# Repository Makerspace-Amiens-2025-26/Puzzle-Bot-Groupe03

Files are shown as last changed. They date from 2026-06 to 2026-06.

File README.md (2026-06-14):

# Puzzle Bot

## Description

Puzzle Bot est une machine automatisée capable de détecter, saisir et assembler les pièces d'un puzzle. Le projet combine plusieurs domaines techniques : conception mécanique, électronique, programmation, vision par ordinateur et fabrication numérique.

## Objectifs
* Détecter les pièces d'un puzzle à l'aide d'une caméra.
* Identifier leur position et leur orientation.
* Déplacer les pièces grâce à un système robotisé.
* Assembler automatiquement le puzzle.
## Technologies utilisées
* Arduino
* Python
* OpenCV
* Onshape
* Impression 3D 
* Découpe laser
## Structure du projet 
* /CAO : modèles 3D et plans.
* /Code : programmes de contrôle et de vision.
* /Electronique : schémas et câblage.
* /Documentation : rapports, poster et ressources.
## Équipe
* Moutassi joseph 
* Mbognie Donna
* Fokem bracins
* Antoni calvin
* Andy Metogo
* Elsy Kounda
## Ressources
* Documentation du projet
* Modèle Onshape
* Poster de présentation

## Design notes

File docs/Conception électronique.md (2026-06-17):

---
layout: default
nav_order: 2
parent: Conception et prototypage
title: Conception electronique
---

# **II. Conception électronique**

## Câblage et Connexions Électriques

Cette section détaille le branchement de chaque composant, fil par fil, pour permettre de reproduire l'électronique du robot à l'identique.

### 1. Alimentation et Arrêt d'Urgence
Toute la puissance mécanique du robot dépend de la batterie 12,7 V. L'objectif est de pouvoir tout couper d'un seul coup.

* **L'Arrêt d'urgence :** Il est placé en "série" sur le fil positif. 
  * Le fil Rouge (+) provenant de la batterie se branche sur l'entrée du bouton coup de poing.
  * En sortie du bouton, le fil Rouge (+) se divise en deux : un câble part vers le bornier d'alimentation du CNC Shield, et l'autre part vers le bornier d'alimentation de notre carte sur mesure (PCB).
* **La Masse :** Le fil Noir (-) de la batterie est directement relié aux borniers "GND" du CNC Shield et de la carte sur mesure.
* **L'Arduino :** Il est alimenté séparément avec son câble USB classique branché à l'ordinateur (qui fournit le 5 V de sécurité).
  
ing1

### 2. Le Cerveau : Arduino et CNC Shield
Le branchement principal est le plus simple : la carte d'extension **CNC Shield v3** vient simplement s'emboîter directement sur le dessus de la carte **Arduino Uno**. Il faut juste vérifier que toutes les petites broches en métal rentrent bien dans les trous noirs de l'Arduino sans se tordre.

### 3. Les Moteurs de déplacement (Axes X et Y)
Ce sont les gros moteurs (NEMA 17) qui font bouger le robot sur la table.

* **Les Drivers (A4988) :** On enfonce ces petits modules sur les emplacements marqués `X` et `Y` au centre du CNC Shield. *(Attention à mettre la petite vis de réglage du bon côté selon la documentation du module !)*
* **Les Moteurs :** Chaque moteur possède un câble avec un connecteur à 4 fils (les deux bobines internes). Ils viennent se brancher directement sur les 4 petites broches alignées juste à côté de leur driver A4988 respectif. Notez à inverser les deux fils du milieu.

ing1

### 4. La Tête de Préhension (Les 2 Servomoteurs)
Les deux servomoteurs (MG996R) qui gèrent la descente et la rotation de la ventouse possèdent 3 fils chacun :

* **Fil Rouge (Énergie) :** À brancher sur une broche **5V** libre du CNC Shield.
* **Fil Marron ou Noir (Masse) :** À brancher sur une broche **GND** du CNC Shield.
* **Fil Jaune ou Orange (Signal) :** C'est le fil qui transporte les ordres. Puisque les broches classiques sont déjà utilisées, on les branche sur des broches libres capables de faire varier la tension (PWM). Par exemple, le premier sur la broche **5** et le deuxième sur la broche **6**.

ing1

### 5. L'Aspiration (La carte sur mesure / PCB)
C'est la carte qui fait l'intermédiaire avec le 12,7 V pour gérer la pneumatique.

* **Les Actionneurs :** * Les 2 fils de la **Pompe à vide** se vissent dans le bornier de sortie (souvent appelé "M1" sur la carte).
  * Les 2 fils de l'**Électrovanne** se vissent dans l'autre bornier de sortie ("M2").
* **La Commande depuis l'Arduino :** On utilise 3 petits fils pour relier cette carte à l'Arduino :
  * Le fil de référence (GND) du PCB se branche sur une broche **GND** libre du Shield.
  * Le fil qui commande l'allumage de la **pompe** est branché sur la broche **A3** (broche analogique de l'Arduino).
  * Le fil qui commande l'ouverture de la **vanne** est branché sur la broche **A4** (broche analogique de l'Arduino).

ing1
### 6. Les Sécurités (Capteurs de fin de course)
Ce sont les interrupteurs qui disent au robot quand il touche les bords de la table. Ils n'ont que 2 fils (connectés sur les pattes "Normalement Ouvert" et "Commun" de l'interrupteur).

* **Capteur de l'axe X :** Les deux fils se branchent sur la zone "End Stops" du CNC Shield. Un fil sur la broche **X+** et l'autre sur la broche **GND** située juste en dessous. *(En code, cela correspond à la broche 9)*.
* **Capteur de l'axe Y :** Un fil sur la broche **Y+** et l'autre sur le **GND** correspondant. *(En code, cela correspond à la broche 10)*.

ing1

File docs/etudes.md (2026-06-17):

---
layout: default
nav_order: 3
title: Études et choix techniques
has_children: true
---

## **ÉTUDE ET CHOIX TECHNIQUE**

## I. Cahier des charges – Projet Puzzle Bot
## 1. Contexte

Ce projet s'inscrit dans une démarche d'apprentissage en ingénierie mêlant mécanique, électronique, informatique et vision par ordinateur.

## 2. Objectif

Développer un système automatisé capable de :

* Détecter les pièces d'un puzzle à l'aide d'une caméra.
* Identifier leur position et leur orientation.
* Déterminer leur emplacement dans l'image finale.
* Manipuler les pièces avec précision.
* Assembler progressivement le puzzle sans intervention humaine.
## 3. Besoins fonctionnels
Fonction principale:
* Résoudre automatiquement un puzzle à partir de pièces disposées sur une zone de travail.

Fonctions secondaires:
* Acquérir des images du plateau.
* Traiter les images pour identifier les pièces.
* Déplacer un outil de préhension sur les axes X et Y.
* Saisir et déposer les pièces avec précision.
* Contrôler les moteurs et les capteurs.
* Permettre le démarrage et l'arrêt du système.
## 4. Contraintes techniques
Mécaniques
* Structure rigide et stable.
* Déplacement précis sur l'ensemble de la zone de travail.
* Système de préhension adapté aux pièces de puzzle.
Électroniques
* Utilisation d'une carte de contrôle (Arduino ou équivalent).
* Alimentation sécurisée.
* Communication entre les différents modules.
Informatiques
* Développement d'un programme de contrôle.
* Utilisation d'algorithmes de vision par ordinateur.
* Interface de configuration et de supervision.
## 5. Performances attendues
* Précision de positionnement 
* Détection fiable des pièces 
* Fonctionnement continu sans intervention humaine.
* Assemblage progressif et reproductible.
## 6. Sécurité
* Protection des parties mobiles.
* Arrêt d'urgence accessible.
* Alimentation électrique sécurisée.
* Respect des règles de sécurité du MakerSpace.
## 7. Livrables
* Modèle CAO complet sur Onshape.
* Schémas électroniques.
* Code source documenté.
* Documentation technique.
* Poster de présentation.
* Vidéo de démonstration.
* Prototype fonctionnel.

# II. Choix techniques de conception

## 1. LA MÉCANIQUE
Les choix techniques concernant la conception de notre machine ont été réalisés de manière progressive après l'identification des différents besoins du projet ainsi que des contraintes liées aux mouvements, à la précision de positionnement et à l'intégration des composants mécaniques et électroniques.

## Structure mécanique

Le châssis principal est constitué de profilés en aluminium, offrant à la fois rigidité. De nouveaux pieds supports ont été conçus afin de surélever le plateau de travail. Cette modification permet le passage des éléments de transmission et facilite le déplacement des différents axes de la machine.

PLATEAU SUPPORT

## Système de déplacement

Le déplacement suivant l'axe X est assuré par un moteur pas à pas. Le système est composé de deux rails latéraux reliés entre eux par un profilé aluminium et une barre métallique. Cette barre est directement couplée à l'arbre moteur à l'aide de deux coupleurs d'arbre, garantissant une transmission synchronisée du mouvement sur l'ensemble de l'axe.

PLATEAU SUPPORT

## Tête de préhension

La tête de préhension a été conçue pour assurer la manipulation et le positionnement des pièces du puzzle. Elle comprend :
- Un système pignon-crémaillère permettant le déplacement vertical de la ventouse.
- Un support orientable pour la ventouse afin d'ajuster l'orientation des pièces.
- Un support pour la pompe à vide et l'électrovanne assurant la préhension des pièces.
- Un moteur pas à pas permettant le déplacement de la tête suivant l'axe Y.

PLATEAU SUPPORT

Cette conception permet de saisir, déplacer et positionner les pièces avec précision sur la zone d'assemblage.

## Boîtier électronique

Un boîtier électronique a été conçu pour regrouper et protéger l'ensemble des composants de commande. Il comprend :

- Un support pour le bouton d'arrêt d'urgence.
- Un support pour la carte de contrôle.
- Un support pour les capteurs de fin de course.
  
 PLATEAU SUPPORT

Un support dédié au profilé de maintien de la caméra ainsi qu'à son système de fixation.

 PLATEAU SUPPORT
 
Cette organisation facilite le câblage de l'ensemble du système.

##  2.l'ÉLECTRONIQUE 

## Électronique : Choix Techniques 

L'électronique du robot Puzzle-Bot a été pensée pour répondre à trois besoins simples : bouger avec précision, gérer l'aspiration des pièces, et garantir la sécurité de tous. 

### 1. Le "Cerveau" du robot (Arduino Uno + CNC Shield)
* *Notre choix :* Un Arduino Uno (carte très classique) sur lequel on a clipsé une carte d'extension appelée "CNC Shield".
* *Pourquoi ce choix ?* L'Arduino est amplement suffisant pour recevoir des ordres simples de l'ordinateur et piloter les moteurs. Le CNC Shield agit comme une grosse "multiprise" bien rangée. Au lieu d'avoir un plat de spaghettis de fils partout, cette carte permet de brancher proprement les moteurs et les capteurs. Si une pièce grille, on peut la remplacer en quelques secondes.

 PLATEAU SUPPORT
### 2. Le contrôle des mouvements (Drivers A4988)
* *Notre choix :* Des petits modules appelés "A4988" pour piloter les moteurs.
* *Pourquoi ce choix ?* Ces modules servent d'intermédiaires entre le cerveau (l'Arduino) et les moteurs. Ils ont deux gros avantages : 
  1. On peut régler précisément l'énergie envoyée aux moteurs pour éviter qu'ils ne surchauffent.
  2. Ils permettent de diviser les mouvements des moteurs en "micro-pas". Cela donne des déplacements très fluides et très précis, ce qui est indispensable pour emboîter des pièces de puzzle.
 PLATEAU SUPPORT
### 3. La gestion de l'aspiration (Carte sur mesure plutôt que des relais)
* *Notre choix :* On a fabriqué notre propre petite carte électronique (avec des composants appelés MOSFETs) au lieu d'acheter des interrupteurs automatiques classiques (relais).
* *Pourquoi ce choix ?*Tout d’abord, nous avons remarqué que notre alimentation de 12.7 V était très importante pour la pompe. Pour éviter de griller la pompe, nous avons du fabriquer une carte électronique afin de commander les mosfets pour le bon fonctionnement de système d’aspiration. Ensuite, nous avons également fait ce choix pour lâcher la pièce de puzzle au bon endroit, la vanne doit s'ouvrir instantanément. Les relais mécaniques sont trop lents et finissent par s'user. Nos composants (MOSFETs) fonctionnent comme des interrupteurs ultra-rapides et silencieux. De plus, on y a soudé des composants de protection (diodes) car les pompes créent des chocs électriques quand on les éteint, ce qui pourrait griller notre circuit.
 PLATEAU SUPPORT
(https://postimg.cc/fVRjxhpt)

### 4. Deux circuits électriques séparés
* *Notre choix :* On utilise deux alimentations totalement séparées.
* *Pourquoi ce choix ?* C'est une question de stabilité. On a séparé l'énergie en deux circuits :
  * Un petit circuit "calme" (USB) pour le cerveau (l'Arduino).
  * Un gros circuit "musclé" (Batterie 12,7 V) pour les moteurs et la pompe.
  Si tout était sur le même circuit, l'effort soudain d'un moteur ou de la pompe ferait chuter le courant et ferait redémarrer ("planter") l'Arduino. En séparant les deux, le cerveau reste protégé des variations d'énergie.

### 5. Le bouton d'Arrêt d'Urgence
* *Notre choix :* Un bouton "d’arrêt d’urgence" qui coupe physiquement le fil du gros circuit (12,7 V).
* *Pourquoi ce choix ?* On ne fait pas confiance au code pour la sécurité ! Si on avait programmé l'arrêt dans l'Arduino et que celui-ci "plante", le bouton ne servirait à rien. En coupant directement le fil d'alimentation général des moteurs, on est certain qu'appuyer sur le bouton arrêtera tout, quoi qu'il arrive dans l'ordinateur.
 PLATEAU SUPPORT

### 6. Le choix des moteurs (Pas à pas et Servomoteur)
* *Notre choix :* Des moteurs "pas à pas" (NEMA 17) pour déplacer le bras sur la table, et deux petits "servomoteurs" (MG996R) pour tourner la pièce de puzzle et le deuxième qui permet le mouvement de translation de la ventouse pour qu’il puisse aller chercher la pièce.
* *Pourquoi ce choix ?* * *Les moteurs pas à pas :* Ils tournent cran par cran (comme les aiguilles d'une montre). En comptant le nombre de crans envoyés, l'ordinateur sait exactement à quel endroit de la table se trouve le robot, au millimètre près, sans avoir besoin de caméras ou de capteurs complexes pour se repérer.
* *Le servomoteur :* Il est très léger et possède une intelligence intégrée qui lui permet de tourner à un angle très précis. Il est parfait pour pivoter la pièce de puzzle (ex: "tourne de 45 degrés") au bout du bras, sans alourdir la machine.
 PLATEAU SUPPORT
 PLATEAU SUPPORT
### 7. Les capteurs de fin de course
* *Notre choix :* Des petits interrupteurs mécaniques placés aux extrémités des axes de déplacement.
* *Pourquoi ce choix ?* Les moteurs pas à pas sont "aveugles" : quand on allume la machine, le robot ne sait pas où se trouve son bras. Il a donc besoin d'un point de repère. Au démarrage, le robot bouge jusqu'à venir taper doucement contre ces interrupteurs. Dès que le bouton fait "clic", le robot sait qu'il est arrivé à son point de départ (le point Zéro). Cela sert aussi de sécurité pour empêcher le robot de continuer à forcer et de s'écraser contre les bords de sa propre structure.
 PLATEAU SUPPORT

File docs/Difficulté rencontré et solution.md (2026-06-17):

---
layout: default
nav_order: 7
title: Difficulté rencontré et solution 
---

## **Difficulté rencontré et solution**

# Difficultés rencontrées et solutions apportées

## Difficultés rencontrées

Au cours du développement du Puzzle Bot, plusieurs difficultés techniques ont été rencontrées.

### Conception mécanique

Les premières versions de certaines pièceson ete decouper au laser en bois etensuite imprimées en 3D présentaient des problèmes de dimensions et d'assemblage. Certaines pièces manquaient de rigidité et ne permettaient pas un maintien correct des composants.

### Alignement des axes

L'alignement des rails et des systèmes de guidage a nécessité plusieurs ajustements afin de garantir un déplacement fluide et précis de la tête de préhension.

### Intégration des composants

L'intégration des moteurs, de la caméra, de la pompe à vide et de l'électronique dans un espace réduit a demandé plusieurs modifications de la conception initiale.

### Réglage des transmissions

Le réglage des courroies et des éléments de transmission s'est révélé plus complexe que prévu. Une tension insuffisante entraînait des imprécisions dans les déplacements tandis qu'une tension excessive augmentait les efforts mécaniques.

### Fabrication des pièces
Certaines impressions 3D ont échoué en raison de défauts d'adhérence au plateau ou de problèmes de conception nécessitant une modification des modèles CAO.

## Solutions apportées

### Amélioration des pièces imprimées

Plusieurs itérations de conception ont été réalisées afin de renforcer les pièces critiques et d'améliorer leur compatibilité avec les composants utilisés.

### Optimisation de la structure

Des renforts ont été ajoutés sur certaines zones du châssis afin d'améliorer la rigidité de l'ensemble et de limiter les vibrations.

### Modification des supports

Les supports moteurs, les supports de caméra et les supports électroniques ont été redessinés afin de faciliter leur montage et leur maintenance.

### Réglage et calibration

Des phases de réglage et de calibration ont été réalisées pour ajuster l'alignement des axes, la tension des courroies et le fonctionnement des moteurs et on a opteur pour un coupleur d'arbre pour uniformisé le mouvement des rails.

### Validation par essais

Chaque modification a été testée sur prototype avant d'être intégrée à la version finale. Cette méthode a permis d'identifier rapidement les problèmes et de valider les solutions retenues.

## Bilan

Malgré les difficultés rencontrées, les différentes phases d'essais et d'amélioration ont permis d'obtenir une machine plus fiable, plus rigide et mieux adaptée aux objectifs du projet. Ces contraintes ont également permis d'acquérir une meilleure compréhension des problématiques liées à la conception et à la réalisation d'un système automatisé.
Les essais ont consisté à comparer différentes versions des pièces afin d'évaluer leur rigidité, leur facilité d'assemblage et leur compatibilité avec les profilés aluminium, les moteurs et les autres éléments de la structure. Les pièces présentées ci-dessous illustrent les différentes itérations réalisées au cours du projet.

<p align="center">

</p>

<p align="center">

</p>

<p align="center">

</p>

<p align="center">

</p>

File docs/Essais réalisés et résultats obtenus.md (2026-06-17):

---
layout: default
nav_order: 5
title: Essais réalisés et résultats obtenus
---

## **Essais réalisés et résultats obtenus**

Afin de valider les différentes pièces de la machine, plusieurs prototypes ont été réalisés par impression 3D. Les premières versions des supports ont permis de vérifier les dimensions, les interfaces de fixation ainsi que l'intégration des composants mécaniques et électroniques.

#  Mécanique
Les essais ont consisté à comparer différentes versions des pièces afin d'évaluer leur rigidité, leur facilité d'assemblage et leur compatibilité avec les profilés aluminium, les moteurs et les autres éléments de la structure. Les pièces présentées ci-dessous illustrent les différentes itérations réalisées au cours du projet.
<p align="center">

</p>

Différentes versions de supports imprimés en bois pour le dispositif de prehesion 
la piece en bois n'ai pas pu stabilise a structure et cella s'est donc soldé par un echec
<p align="center">

</p>
les pieces on eté revue et ameeliorer en impression impression 3d et cella nous a aussi permis d'integere directement le capteur fin de courses 
<p align="center">

</p>
la tete de prehension a ete pensé en suport fixe avec un gros chassis cella ne nous a pas permis d'inrtegrer le deplagement et la rotation des pieces saisis cet option a donc ete un echec 
<p align="center">

</p>
Les résultats obtenus ont permis d'identifier plusieurs améliorations à apporter, notamment le renforcement de certaines zones mécaniques, l'ajout de points de fixation supplémentaires et l'optimisation de la géométrie de certaines pièces pour faciliter leur montage.

Après plusieurs phases de test et de modification, les pièces finales ont répondu aux exigences de résistance, de précision et d'intégration nécessaires au bon fonctionnement de la machine. Ces essais ont également permis de réduire les risques d'erreur lors de l'assemblage final et d'améliorer la fiabilité globale du système.

#  Electronique

Pour commander la pompe et l'électrovanne, nous avons utiliser un module L91105 mais malheureusement qui n'a pas permis le bon fonctionnement de ceux-ci.


1. Pourquoi utiliser le L9110S au début ?
   
Le L9110S est un Double Pont en H. On l'a choisi initialement pour plusieurs raisons :
 * Disponibilité : C'est un composant très commun dans les kits Arduino.
 * Polyvalence : Il possède deux canaux indépendants, ce qui permet de contrôler deux charges (pompe + vanne) avec une seule carte.
 * Interface simple : Il communique très facilement en niveaux logiques avec l'Arduino.
 
2. Pourquoi cela ne fonctionne pas pour le projet ?
   
Le L9110S a atteint ses limites physiques pour plusieurs raisons critiques :
 Le courant d'appel: Au démarrage, une pompe à vide et une électrovanne consomment beaucoup plus de courant que lorsqu'elles sont en régime établi. Le L9110S a une capacité de courant limitée (généralement < 800mA). Le pic de démarrage fait surchauffer, voire griller instantanément la puce.
 Les charges inductives (Force contre-électromotrice) : Contrairement à une LED, une pompe ou une vanne contient une bobine. Quand tu coupes l'alimentation, la bobine décharge une pointe de tension extrêmement élevée (plusieurs centaines de volts). Le L9110S n'a pas de protection interne suffisante contre ces retours de courant, ce qui finit par détruire les transistors du module.
 
3. La solution pour résoudre ce problème

Pour resoudre ce problème, nous avons utiliser des MOSFETs de puissance (type N-Channel) plus Précisement le ZVN4306A avec une diode de roue libre.
Pourquoi c'est mieux :
 * Résistance ultra-faible : Le MOSFET laisse passer quasiment tout le courant. La pompe reçoit les 12.7V réels.
 *  Robustesse : Un MOSFET de puissance peut gérer des courants bien plus élevés et ne craint pas la chauffe comme le petit module L9110S.
 * La Diode de Roue Libre (Crucial) : On ajoute une diode  aux bornes de la pompe/vanne. Elle sert de "soupape de sécurité" qui boucle le courant de retour de la bobine lors de l'extinction, protégeant ainsi tout ton système.

  (https://postimg.cc/qt6Fx0n2)

# Programmation

* *Génération des pas :* La génération des signaux Step et Dir a été gérée de façon optimisée pour garantir la fluidité sans alourdir le processeur de l'Arduino.
* *Gestion des Servomoteurs :* L'utilisation de la bibliothèque Servo.h a facilité la conversion des angles issus de la vision en signaux PWM.
* *Synchronisation Pneumatique :* L'arrêt de la pompe ne suffisant pas à relâcher la pièce à cause de l'air résiduel, le programme ouvre l'électrovanne juste après l'arrêt de la pompe afin de "casser le vide" instantanément.
  
pour y remedier nous avons mis sur pied une interface grafique afin de controler distintement chaque dospositif pour pouvoir mieux uunifrmioser le deplacement de la machines 

(https://postimg.cc/XrSx6Fyn)

## Résultats obtenus

- Validation des dimensions des pièces imprimées.
- Vérification de la compatibilité avec les profilés aluminium.
- Amélioration de la rigidité des supports.
- Optimisation de l'assemblage des composants mécaniques.
- Réduction des risques d'interférence entre les différentes pièces.
- Validation des solutions retenues pour la version finale de la machine.

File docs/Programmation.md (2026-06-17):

---
layout: default
nav_order: 3
parent: Conception et prototypage
title: programmation
---

# III. programmation  

##  Architecture et Logique

La partie logicielle du Puzzle-Bot est divisée en deux niveaux distincts qui communiquent ensemble : un niveau "Haut" (le cerveau analytique sur ordinateur) et un niveau "Bas" (l'exécutant mécanique sur l'Arduino).

### Architecture Logicielle Globale

* *Le Traitement d'Image (Haut Niveau) :* Un programme tournant sur l'ordinateur utilise la caméra pour détecter la position des pièces, calcule leur orientation, et détermine les coordonnées et l'angle de rotation nécessaires.
* *La Communication Série :* L'ordinateur traduit ces coordonnées en instructions textuelles et les envoie à la carte Arduino via un câble USB.
* *Le Contrôle Mécanique (Bas Niveau) :* Le code de l'Arduino traduit les instructions en signaux électriques (PWM, impulsions de pas, commandes statiques).

Capture-d-ecran-2026-06-14-16
Modélisation du boîtier électronique 
### Séquençage et Machine d'États (Le Cycle de Travail)

Le code de l'Arduino est structuré comme une "machine d'états". Le robot exécute une séquence d'actions stricte pour chaque pièce de puzzle, avec des temporisations ajustées pour la gestion du vide pneumatique.

Modélisation du boîtier électronique 

### Gestion des Sécurités Logicielles (Homing)

Avant de pouvoir placer une pièce, une routine d'initialisation (Homing) s'exécute :
1.  *Recherche du Zéro :* L'Arduino fait reculer les moteurs très lentement.
2.  *Détection :* L'écrasement des capteurs de fin de course stoppe les moteurs.
3.  *Calibrage :* Cette position physique devient le point de coordonnées (0,0) de référence pour tous les futurs déplacements.

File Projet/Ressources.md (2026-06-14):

## Ressources du Projet

Cette section regroupe l'ensemble des fichiers techniques, des nomenclatures et des codes sources nécessaires pour comprendre, évaluer en détail ou reproduire intégralement le robot Puzzle-Bot.

### 1. Conception Mécanique

Cette partie contient les modélisations 3D de la structure, des pieds sur mesure et de la tête de préhension.
* **Fichiers CAO natifs :** [Lien vers les fichiers sources du logiciel de modélisation 3D]

* **Fichiers pour impression 3D :** [Lien vers les fichiers .STL des pièces fabriquées]

### 2. Électronique

Cette partie regroupe les éléments de la chaîne d'énergie, de commande, et de la carte sur mesure.
* **Nomenclature (BOM) :** [Lien vers le tableur listant les composants : CNC Shield, NEMA 17, MG996R, relais/MOSFETs, etc.]
* **Fichiers de conception (KiCad) :** [Lien vers le schéma électrique et le fichier de routage du PCB](https://www.kicad.org/)
* **Fichiers de fabrication :** [Lien vers les fichiers Gerber de la carte de puissance]()

### 3. Programmation

Cette partie détaille l'environnement logiciel nécessaire pour compiler et exécuter le projet.
* **Environnements de développement :** [Arduino IDE, environnement ](https://www.arduino.cc/en/software)
* **Bibliothèques (Libraries) requises :** [Lister les dépendances, ex: Servo.h pour les servomoteurs, librairies de traitement d'image]
* **Logique et algorithmes :** [Lien vers les diagrammes d'états ou algorithmes de détection]

### 4. Code Source

Cette partie contient l'accès direct aux scripts qui pilotent la machine.
* **Code Bas Niveau (Contrôle) :** [Lien vers le dossier des fichiers Arduino `.ino` gérant la cinématique et la pneumatique]
* **Code Haut Niveau (Vision) :** [Lien vers le dossier des scripts gérant l'analyse d'image, le calcul d'angle et la génération de coordonnées]

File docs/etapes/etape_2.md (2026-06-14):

---
layout: default
title: Assemblage
parent: Etapes de fabrication
nav_order: 2
---

# Assemblage

Après la préparation des matériaux, l'étape suivante est l'assemblage.

## Étapes d'Assemblage

1. **Organisation** : Organisez tous les composants préparés.
2. **Assemblage Initial** : Commencez par assembler les pièces principales.
3. **Fixation** : Fixez solidement les pièces ensemble en utilisant les outils appropriés.

# Assemblage du Puzzle Bot

Après la préparation des matériaux, l'étape suivante est l'assemblage complet de la machine. Cette phase permet de donner vie au robot en combinant la structure mécanique, les pièces imprimées en 3D et le système d'aspiration.

---

##  1. Organisation du Poste de Travail

Avant de commencer le montage, préparez un espace propre et bien rangé au MakerSpace. Cela évite de perdre des pièces ou de faire des erreurs.

* **Trier les pièces :** Mettez d'un côté la quincaillerie (vis et écrous classés par taille) et de l'autre les morceaux du châssis en aluminium ainsi que toutes les pièces imprimées en 3D.
* **Protéger les éléments fragiles :** Gardez les cartes électroniques à l'écart pendant que vous montez la structure lourde. Cela évite de faire tomber des petits morceaux de métal ou des outils dessus.

---

##  2. Assemblage Initial (Le Châssis et les Axes X-Y)

Pour obtenir une machine stable, nous avons repensé la base afin de créer un système de portique qui quadrille parfaitement notre zone de travail.

### Le Cadre et le Quadrillage de la Zone (Axe X)
* **Les nouveaux coudes d'angle (Corners) :** Commencez par installer les nouveaux coudes en plastique conçus en 3D aux quatre coins de la planche en Plexiglas. Ils servent à maintenir fermement les deux grands profilés en aluminium parallèles. Cela crée un cadre rigide et un repère fixe pour délimiter la zone de travail.
    
* **Le profilé mobile et ses supports à roues :** Prenez le profilé en aluminium qui traverse la machine pour l'axe X. Fixez à ses deux extrémités les deux pièces 3D spécifiques sur lesquelles sont vissées des roues de guidage. Emboîtez ces roues dans les rails du cadre. Pour motoriser ce déplacement, l'une de ces deux pièces d'extrémité est dotée d'un moteur pas-à-pas. Ainsi, ce côté est entraîné directement par le moteur, ce qui permet de déplacer l'ensemble du profilé mobile de manière fluide sur l'axe X, tout en le maintenant bien droit et sans qu'il ne se mette de travers.

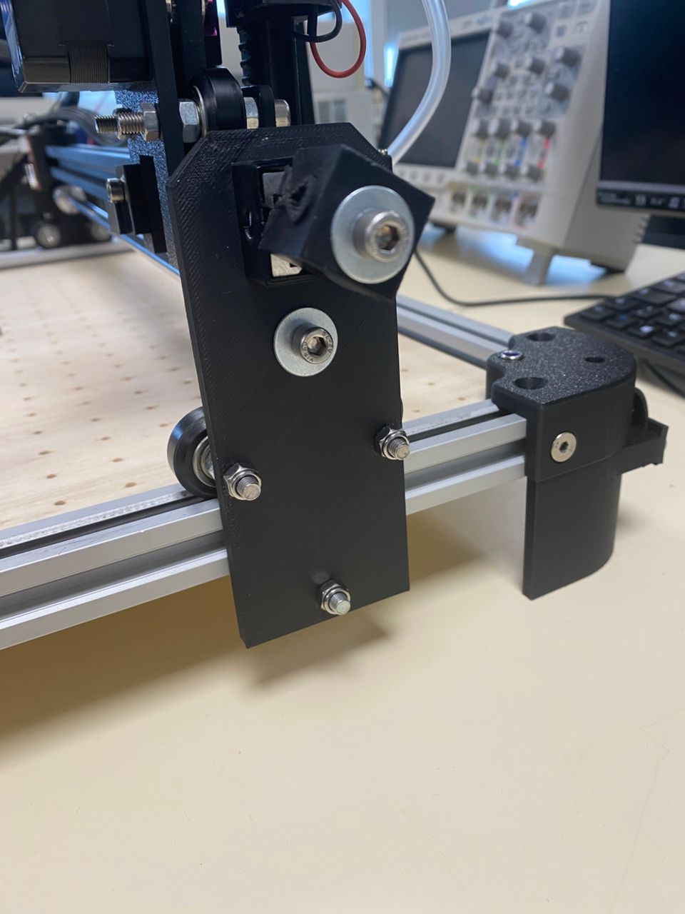
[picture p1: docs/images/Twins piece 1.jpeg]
  

###  Le Chariot Mobile (Axe Y)
* **Le bloc central coulissant :** Assemblez le groupe de pièces 3D autour du profilé mobile. Une fois vissées ensemble, ces pièces forment un unique bloc compact qui glisse de gauche à droite sur l'axe Y. C'est ce bloc qui porte tout le système de l'axe Z (la pompe, l'électrovanne et la ventouse) pour déplacer les pièces de puzzle.
  
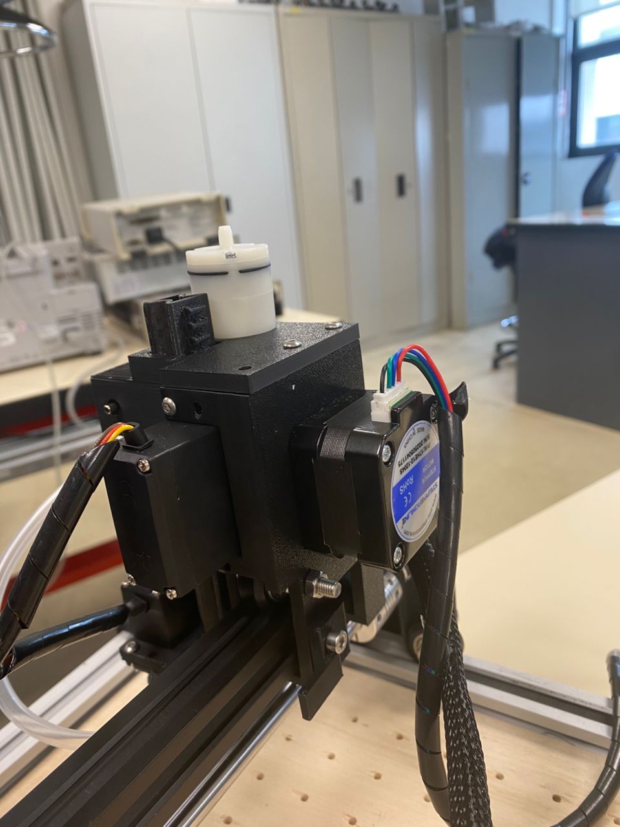
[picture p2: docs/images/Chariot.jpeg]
  

##  3. Fixation et Montage de l'Axe Vertical (Z) et de ses Outils

L'axe Z est installé directement sur le chariot de l'axe Y. Il gère la descente de tout le système pour aspirer et déplacer les pièces.

* **Le montage de l'axe Z :** Installez les glissières verticales sur le chariot de l'axe Y, puis fixez le moteur pas-à-pas qui fait monter et descendre le système d'aspiration.
* **L'installation de la pompe et de la vanne :** Fixez la mini-pompe à air et l'électrovanne directement sur le chariot mobile. En les plaçant ici, tout le système pneumatique se déplace en même temps que le robot.
* **Le support de la caméra (Suivi du mouvement) :** Fixez la pièce 3D de la caméra sur la partie mobile de l'axe Z. De cette façon, la caméra descend en même temps que la pompe pour suivre précisément la saisie de la pièce de puzzle.

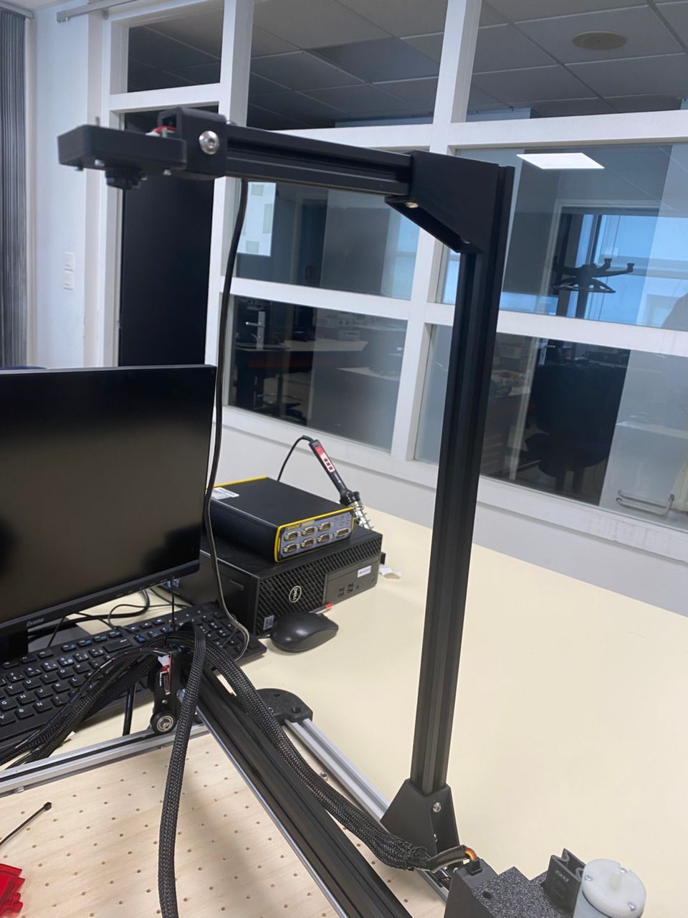
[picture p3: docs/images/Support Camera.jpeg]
  

* **Le support coudé du servomoteur et de la ventouse :** Tout en bas de l'axe Z, installez le support en coude (à 90°) imprimé en 3D. Fixez-y le servomoteur et la ventouse reliée aux tuyaux en silicone. Ce coude permet à la ventouse de tourner la pièce sur elle-même sans la décaler du centre.
---

##  Vérifications Finales

Avant de passer à la suite, effectuez ces derniers contrôles :

* **Vérifier le glissement :** Poussez chaque axe à la main, moteurs éteints. Le mouvement doit être souple et sans effort sur toute la zone de travail. Si ça coince, desserrez un peu les vis, réalignez les profilés et revissez.
* **Vérifier le serrage :** Assurez-vous qu'aucune vis n'a été oubliée et que toutes les pièces 3D sont solidement fixées.

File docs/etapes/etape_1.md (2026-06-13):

---
layout: default
title: Préparation du Matériels
parent: Etapes de fabrication
nav_order: 1
---

# Préparation des Matériaux

Cette section décrit la première étape du processus de fabrication : la préparation des matériaux.

## Liste des Matériaux

| Visuel | Composant | Description & Rôle | Spécifications / Usage |
Voici la liste des composants utilisés pour le projet.

| Visuel | Composant | Description & Rôle | Spécifications / Usage |
| :---: | :--- | :--- | :---: |
|  | **Arduino Uno** | Carte à microcontrôleur principale. C'est le cerveau du robot qui exécute la logique de commande. | 1 unité |
|  | **CNC Shield (V3)** | Carte d'extension pour l'Arduino. Permet de centraliser le câblage et de piloter facilement plusieurs axes. | 1 unité |
|  | **Driver de moteur (A4988 / DRV8825)** | Petit module de puissance s'insérant sur la CNC Shield pour contrôler le courant envoyé aux moteurs pas-à-pas. | 1 par moteur |
|  | **Kit préhenseur pneumatique** | Ensemble comprenant une mini-pompe à vide et une électrovanne (EV) reliées à une ventouse pour la saisie des pièces. | 1 kit |
|  | **Servomoteur** | Actionneur rotatif idéal pour piloter un mouvement angulaire limité (par exemple, l'orientation de la ventouse ou un mécanisme d'échappement). | Selon design |
|  | **Moteur pas-à-pas (NEMA 17)** | Moteur haute précision pour gérer les déplacements linéaires ou angulaires précis des axes du robot. | Selon axes |
|  | **Profilés Aluminium** (Type V-Slot 2020) | Structure principale et axes linéaires du châssis. | 4 x 400mm |

---
## Procédure de Préparation

Cette phase de préparation se divise en trois étapes obligatoires pour sécuriser la fabrication : s'approprier la documentation, valider le matériel par des tests unitaires, puis procéder aux découpes mécaniques.

### 1.  Étude de la Documentation des Matériaux
Avant toute manipulation, il est indispensable de consulter les fiches techniques (*datasheets*) des composants disponibles dans le dossier `docs/datasheets/` du dépôt.
* **Vérification des tensions :** Identifier la tension nominale de chaque élément (5V pour l'Arduino, 12V/24V pour la CNC Shield et la pompe pneumatique).
* ** brochage (Pinout) :** Repérer les broches de commande des drivers et le sens d'insertion sur la CNC Shield pour éviter les inversions.
* **Limites mécaniques :** Prendre connaissance du couple maximal des moteurs pas-à-pas et de la course utile des axes pour ajuster les futurs fins de course.

### 2.  Tests Individuels (Tests Unitaires du Matériel)
Chaque composant doit être validé indépendamment "sur table" avant l'assemblage final.

* **L'Arduino Uno :** Brancher la carte seule en USB. Téléverser un programme servant à allumer les LED par exemple pour s'assurer que le microcontrôleur est fonctionnel.
* **La CNC Shield & Drivers :** Insérer un seul driver. Alimenter la carte en puissance (12V) et mesurer la tension de référence ($V_{ref}$) au multimètre sur le potentiomètre du driver. Ajuster le courant pour qu'il corresponde au courant nominal du moteur pas-à-pas.
* **Les Moteurs Pas-à-Pas :** Connecter un moteur au driver testé, charger un script de rotation simple (Grbl ou script d'essai standard) et vérifier que le moteur tourne sans sauter de pas ni surchauffer.
* **Le Kit Pneumatique :** Alimenter brièvement la mini-pompe en 12V pour vérifier l'aspiration. Tester le déclenchement de l'électrovanne.
* **Le Servomoteur :** Connecter à l'arduino, lancer un programme visant à le faire tourner 

### 3.  Découpage et Usinage
Une fois l'électronique validée, on prépare la structure physique au MakerSpace.

* **Profilés Aluminium :** Mesurer et marquer les longueurs de profilés nécessaires à l'aide d'un trusquin ou d'un réglet de précision. Effectuer la découpe à la scie à ruban ou à la scie circulaire à métaux. Ébavurer soigneusement les bords à la lime plate.
* **Plaques de Support (Plexiglas/PMMA) :** Exporter les plans de la base du robot au format `.DXF`. Charger le fichier dans le logiciel de la découpeuse laser du MakerSpace. Ajuster la vitesse et la puissance selon l'épaisseur de la plaque pour obtenir une coupe nette sans brûlure.
* **Pièces Imprimées 3D :** Générer les fichiers `.GCODE` via le slicer (Cura, PrusaSlicer) pour les pièces de fixation. Lancer les impressions et retirer délicatement les supports à la pince coupante.

## Conseils de Sécurité & Gestion des Blocages
### 1. Sécurité Électrique : Protection du Matériel
* **Double vérification des alimentations :** Avant de mettre le système sous tension, validez systématiquement les polarités au multimètre. Une inversion de polarité ou une tension trop élevée (ex: envoyer du 12V directement sur une broche 5V de l'Arduino) détruira instantanément vos composants.
* **Manipulations hors tension :** Ne connectez et ne déconnectez **jamais** un moteur pas-à-pas ou un driver de la CNC Shield lorsque la carte est alimentée. Cela crée des arcs électriques internes qui grillent les puces instantanément.

### 2. Sécurité des Machines & Qualité de Fabrication
* **Vérification de l'imprimante 3D :** Avant de lancer une longue impression, inspectez la machine : nettoyage du plateau (adhérence), vérification du niveau du lit (*bed leveling*) et état de la buse. Une mauvaise configuration entraîne des décollages (*warping*) ou des tolérances géométriques faussées, rendant les pièces mécaniques inutilisables pour l'assemblage.
* **Règle de la machine inconnue :** Si une machine nécessaire au projet (découpeuse laser, scie à ruban, thermoformeuse) n'est pas maîtrisée par l'équipe, **il est strictement obligatoire de demander l'aide ou une formation** à un encadrant ou au fabmanager avant toute utilisation. Ne prenez aucun risque inutile.

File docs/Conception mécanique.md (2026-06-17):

---
layout: default
nav_order: 1
parent: Conception et prototypage
title: Conception mecanique
---

# I.Conception mecanique 
## Conception Mécanique

### 1. Structure Principale et Châssis
* *Bâti en profilés d'aluminium :* Le châssis principal est construit à partir de profilés standards. Ce choix garantit une excellente rigidité structurelle tout en conservant une grande modularité pour l'assemblage et l'ajustement des équerrages.
* *Pieds de surélévation sur mesure :* De nouveaux pieds supports ont été spécifiquement conçus et intégrés pour surélever le plateau de travail. Ce dégagement vertical est indispensable : il permet le passage fluide des éléments de transmission sous la zone d'assemblage et facilite le débattement des différents axes de la machine sans risque de collision.

* Vue du châssis et des pieds

### 2. Cinématique de Déplacement (Axes X et Y)
* *Transmission de l'axe X :* Le déplacement longitudinal du portique est piloté par un moteur pas à pas. Pour garantir un mouvement parfaitement translationnel et éviter l'arc-boutement, le système de guidage s'appuie sur deux rails latéraux. La synchronisation de l'entraînement entre les deux côtés est assurée par une barre de transmission métallique, accouplée directement à l'arbre du moteur via deux coupleurs flexibles.
* *Guidage de l'axe Y :* Le moteur pas à pas gérant l'axe transversal (Y) est directement embarqué sur la structure mobile, assurant le déplacement de la tête de préhension sur toute la largeur du portique.

* Détail de la transmission Axe X

### 3. Tête de Préhension (Outil et Axe Z)
La tête de l'effecteur est l'élément central pour la manipulation des pièces. Elle a été compactée au maximum pour intégrer de multiples fonctions mécaniques :
* *Déplacement vertical (Axe Z) :* Un système de pignon-crémaillère a été intégré pour convertir le mouvement de rotation du moteur en un déplacement vertical linéaire de la ventouse.
* Conception de la tête de préhension
* *Rotation de la pièce :* Un support orientable est fixé au bout de la crémaillère pour faire pivoter la ventouse, permettant d'ajuster l'angle de la pièce de puzzle avec précision avant sa pose.
* *Intégration pneumatique :* La tête dispose de supports de fixation dédiés pour embarquer directement la pompe à vide et l'électrovanne. Cette proximité avec la ventouse réduit la longueur du circuit d'air et garantit un temps de réponse immédiat lors de la préhension et du relâchement.

* Conception de la tête de préhension

### 4. Boîtier d'Intégration et Support Caméra
Pour finaliser la machine, la rendre autonome et sécuriser les utilisateurs, un boîtier global a été modélisé :
* *Organisation de l'électronique :* Il comprend les supports de fixation sur mesure pour la carte de contrôle principale, facilitant le routage propre des câbles.
* *Sécurité et Capteurs :* Des emplacements spécifiques et rigides sont prévus pour le maintien des capteurs de fin de course, ainsi qu'une façade accessible pour le bouton d'arrêt d'urgence.
* *Module Vision :* Le boîtier intègre également la base de maintien du profilé vertical dédié à la caméra. Ce système de fixation garantit que l'objectif reste parfaitement stable et centré au-dessus de la zone de travail, ce qui est crucial pour la précision de l'algorithme de détection.

* Modélisation du boîtier électronique

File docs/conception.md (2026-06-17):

---
layout: default
nav_order: 4
title: Conception et prototypage
---

## **CONCEPTION ET PROTOTYPAGE**

La phase de conception du Puzzle Bot a débuté par une analyse des besoins et des contraintes du projet. L'objectif était de développer une machine capable de manipuler et de positionner automatiquement des pièces de puzzle avec précision. Plusieurs solutions techniques ont été étudiées afin de déterminer l'architecture mécanique, les systèmes de déplacement et les composants électroniques les plus adaptés.

Une modélisation complète de la machine a ensuite été réalisée sur Onshape. Cette étape a permis de concevoir le châssis, les supports mécaniques, la tête de préhension et les différents éléments nécessaires à l'intégration des moteurs, de la caméra et des composants électroniques.

Afin de valider les choix de conception, plusieurs prototypes ont été fabriqués par impression 3D. Ces essais ont permis de vérifier les dimensions des pièces, leur compatibilité avec les profilés aluminium ainsi que leur facilité d'assemblage. Plusieurs versions de certains supports ont été réalisées avant d'obtenir une solution satisfaisante répondant aux exigences de rigidité et de précision.

Les phases de prototypage ont également permis d'identifier différentes améliorations, notamment le renforcement de certaines pièces, l'ajout de points de fixation supplémentaires et l'optimisation de l'intégration des composants. Cette démarche itérative a contribué à fiabiliser la conception avant la réalisation de la version finale de la machine.

## Outils utilisés

- Onshape pour la conception CAO.
- Imprimantes 3D pour la fabrication des prototypes.
- Profilés aluminium pour la structure mécanique.
- Moteurs pas à pas pour les déplacements.
- Arduino pour la commande électronique.
- Caméra pour le système de vision.

## Résultats du prototypage

- Validation de l'architecture mécanique.
- Vérification des interfaces entre les composants.
- Optimisation des pièces imprimées en 3D.
- Amélioration de la rigidité de la structure.
- Préparation de la version finale du Puzzle Bot.

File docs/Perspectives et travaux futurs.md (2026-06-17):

---
layout: default
nav_order: 8
title: Perspectives et travaux futurs
---

##  **Perspectives d'Évolution et Améliorations Futures**

Le Puzzle-Bot actuel constitue une preuve de concept fonctionnelle validant nos choix d'architecture. Cependant, pour passer d'un prototype de laboratoire à une machine plus robuste, performante et industrielle, plusieurs pistes d'amélioration ont été identifiées :

### 1. Vision et Intelligence Artificielle
* *Modèles de détection avancés :* Remplacer les algorithmes de détection de formes simples par des modèles de Deep Learning (ex: YOLOv8) pour identifier les pièces de puzzle même en cas d'occlusion partielle ou de faible luminosité.
* *Calibration de la caméra :* Mise en œuvre d'une matrice de correction  afin d'augmenter la précision des coordonnées $(X, Y)$ envoyées au robot.

### 2. Précision Mécanique

* *Gestion des câbles :* Installation de chaînes porte-câbles  imprimées en 3D pour sécuriser les faisceaux électriques et éviter leur usure ou leur accrochage lors des déplacements rapides.
* *Optimisation des matériaux :* Remplacer les pièces structurelles en impression 3D par de l'aluminium usiné pour accroître la rigidité et réduire les vibrations à haute vitesse.

### 3. Fiabilité Électronique

* *Communication sans fil :* Migration du contrôle filaire (USB) vers une liaison sans fil (Wi-Fi ou Bluetooth via ESP32) pour isoler le robot de l'ordinateur de contrôle.

### 4. Logiciel et Optimisation

* *Optimisation des trajectoires (TSP) :* Intégrer un algorithme de résolution pour calculer le trajet optimal permettant de ramasser toutes les pièces dans l'ordre le plus rapide possible.
* *Interface Homme-Machine (IHM) :* Développer une interface graphique en Python ou sur une page web pour piloter le robot, visualiser le retour caméra et suivre l'état d'assemblage en temps réel sans interagir avec le code source.

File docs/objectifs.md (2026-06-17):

---
layout: default
nav_order: 2
title: Présentation Générale du Projet
---

## **Présentation Générale du Projet**

## 1. Introduction

Le projet **Puzzle Bot** consiste à concevoir et réaliser une machine automatisée capable de résoudre un puzzle de manière autonome. Ce projet mobilise plusieurs domaines de l’ingénierie, notamment la conception mécanique, l’électronique, la programmation, la vision par ordinateur et la fabrication numérique. L’objectif est de développer un système complet capable de détecter, manipuler et assembler des pièces de puzzle avec précision.

## 2. Contexte du Projet

Ce projet s'inscrit dans le cadre du programme MakerSpace et vise à mettre en pratique les compétences acquises au cours de la formation. Inspiré de projets open source existants et des problématiques industrielles liées à l'automatisation, Puzzle Bot représente un défi technique multidisciplinaire. Il permet aux étudiants de travailler en équipe sur un projet concret intégrant la conception, le prototypage, les tests et l'amélioration continue d'un système robotisé.

## 3. Objectifs du Projet

Les principaux objectifs du projet sont :

- Concevoir une structure mécanique capable de déplacer un système de préhension avec précision.
- Développer un système de vision permettant de détecter et d'identifier les pièces du puzzle.
- Programmer le contrôle des moteurs, capteurs et actionneurs nécessaires au fonctionnement de la machine.
- Mettre en œuvre un algorithme permettant de déterminer la position des pièces dans le puzzle final.
- Assembler automatiquement les pièces afin de reconstituer l'image du puzzle.
- Développer les compétences techniques et méthodologiques des membres de l'équipe à travers un projet d'ingénierie complet.

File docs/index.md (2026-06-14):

---
layout: home
nav_order: 1
title: Accueil
permalink: /
---

## **BIENVENUE SUR NOTRE DOCUMENTATION**

Bienvenue dans la documentation du projet PUZZLE BOT. Ce site a pour but de fournir toutes les informations nécessaires pour comprendre, utiliser et reproduire efficacement notre projet.

[Notre projet sur Onshape](https://cad.onshape.com/documents/f68d7b4e4c596dbd307bcac0/w/5ce81b40307e52fb876e4acc/e/4f4f3f44fe039d3cdeee6809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) Consultez egalement,
[Notre repo GitHub](https://makerspace-amiens-2025-26.github.io/Puzzle-Bot-Groupe03/)

Poster projet

## À propos du Projet

Le Puzzle-Bot est une machine conçue pour identifier, trier et assembler les pièces d'un puzzle de manière autonome. Ce projet intègre trois domaines de l'ingénierie :
* **Informatique & Vision :** Détection des pièces et calcul des trajectoires via vision par ordinateur.
* **Électronique & Embarqué :** Interfaçage de puissance, commande de moteurs pas à pas et gestion d'actionneurs pneumatiques via microcontrôleur.
* **Conception Mécanique :** realisation et mise au point des composants du système. 

## L'Équipe (Groupe 03)
* Bracins FOKEM & Elsy KOUNDA - Conception mécanique & CAO
* Joseph MOUTASSI & Anthony MVONO - Programmation & Vision par ordinateur 
* Donna MBOGNIE & Andy METOGO - Architecture Électronique

## Poster

Voici le poster de notre projet Puzzle Bot, une machine conçue pour résoudre automatiquement des puzzles

Poster projet

## Vidéo

<video src="images/groupe 3 final.mp4" controls title="Title"  style="width: 100%;"></video>

---

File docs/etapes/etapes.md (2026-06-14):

---
layout: default
title: Etapes de fabrication
nav_order: 6
has_children: true
---

# **ÉTAPES DE FABRICATION**

Bienvenue dans la section dédiée aux étapes de fabrication du projet XYZ. Ici, vous trouverez des guides détaillés pour chaque étape du processus de fabrication.

## Aperçu des Étapes

Le processus de fabrication est divisé en plusieurs étapes clés :

1. [Préparation des Matériaux](etape_1)
2. [Assemblage](etape_2)

## Commencer

Pour commencer, assurez-vous de bien comprendre chaque étape et de disposer de tous les outils et matériaux nécessaires. Suivez les étapes dans l'ordre pour garantir la qualité et l'efficacité du processus de fabrication.

---

Pour toute question ou aide supplémentaire, n'hésitez pas à contacter notre équipe.

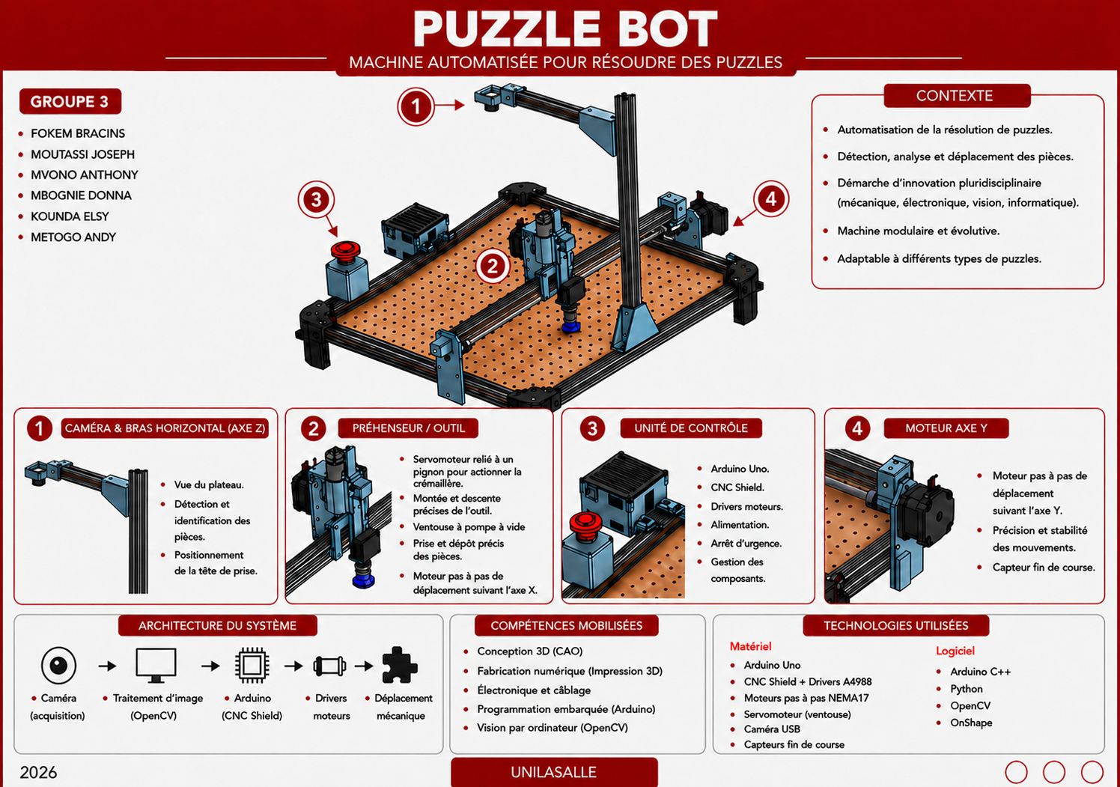
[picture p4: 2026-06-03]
docs/Poster.jpg

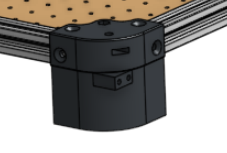
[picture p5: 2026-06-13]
docs/images/Capture d'écran 2026-06-13 131632.png

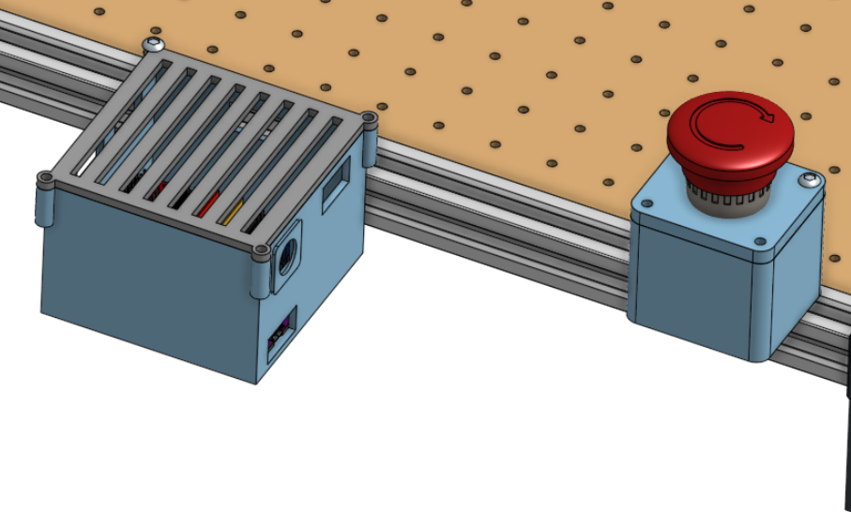
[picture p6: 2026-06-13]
docs/images/Capture d'écran 2026-06-13 200942.png

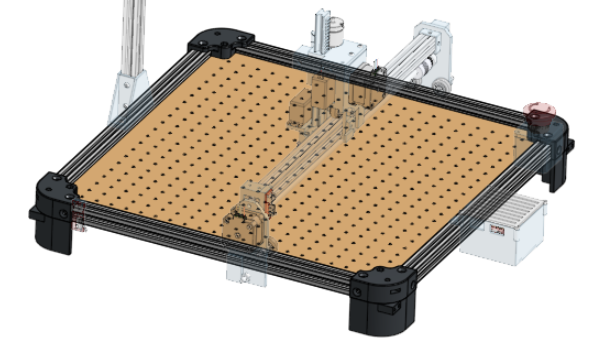
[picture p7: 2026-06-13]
docs/images/Capture d'écran 2026-06-13 232324.png

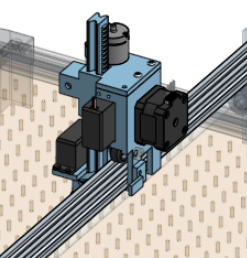
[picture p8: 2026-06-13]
docs/images/Capture d'écran 2026-06-13 233024.png

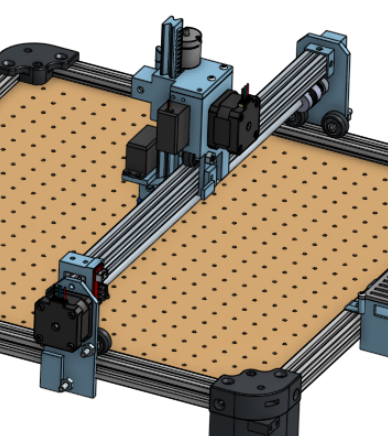
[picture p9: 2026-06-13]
docs/images/Capture d'écran 2026-06-13 220557.png

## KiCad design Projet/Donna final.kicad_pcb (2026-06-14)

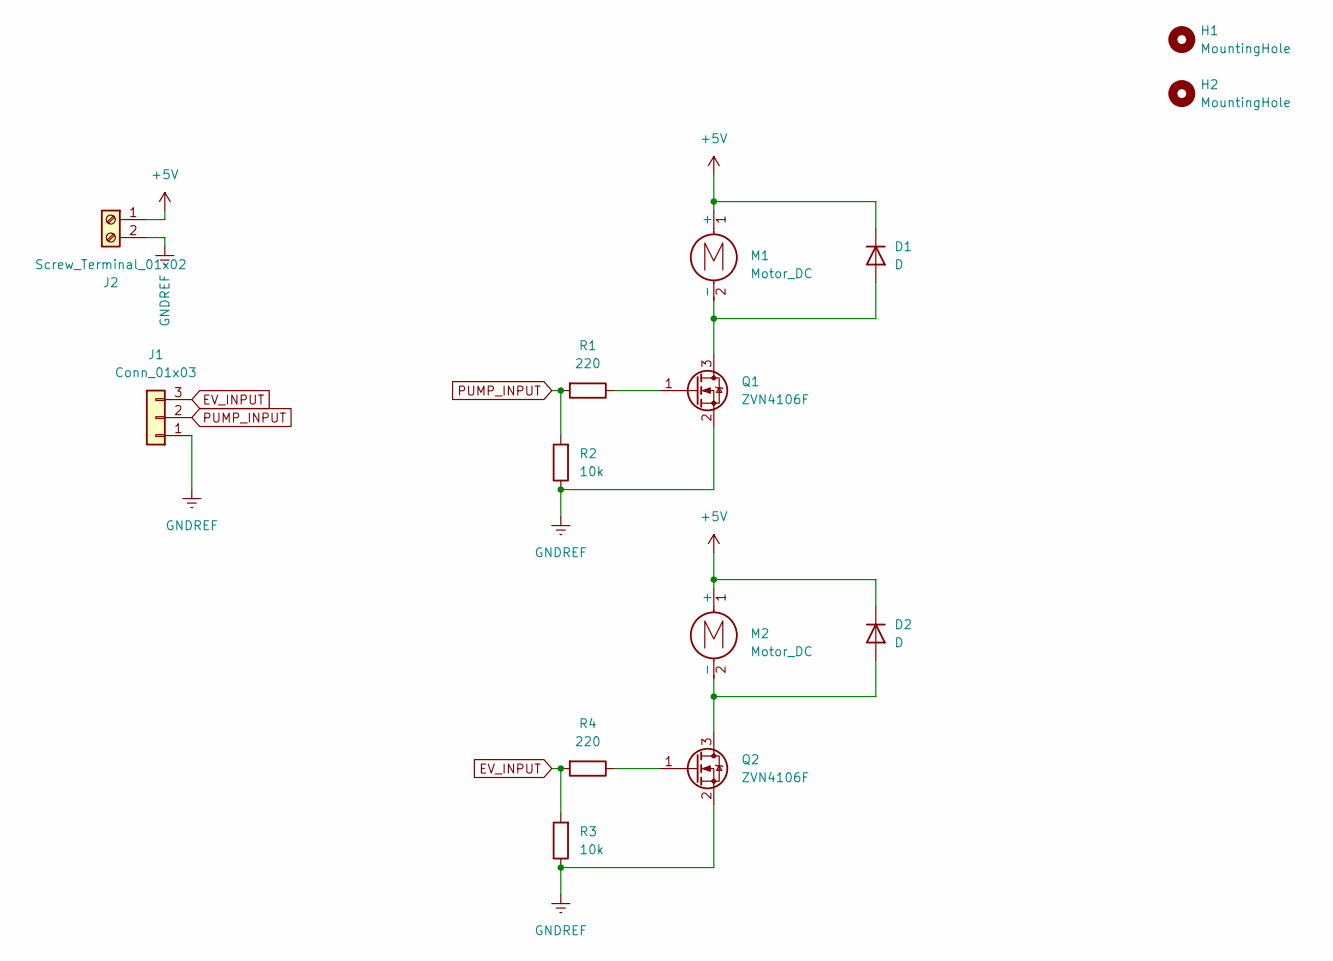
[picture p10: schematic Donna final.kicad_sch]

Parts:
D1, D2: D; D_SMA
H1, H2: MountingHole; MountingHole_3.2mm_M3
J1: Conn_01x03; PinHeader_1x03_P2.54mm_Vertical
J2: Screw_Terminal_01x02; TerminalBlock_Phoenix_PT-1,5-2-5.0-H_1x02_P5.00mm_Horizontal
M1, M2: Motor_DC; TerminalBlock_Phoenix_PT-1,5-2-5.0-H_1x02_P5.00mm_Horizontal
Q1, Q2: ZVN4106F; TO-92L_Inline
R1, R4: 220; R_1206_3216Metric_Pad1.30x1.75mm_HandSolder
R2, R3: 10k; R_1206_3216Metric_Pad1.30x1.75mm_HandSolder

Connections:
+5V: D1.1 (K), D2.1 (K), J2.1, M1.1 (+), M2.1 (+)
EV_INPUT: J1.3, R3.2, R4.2
GNDREF: J1.1, J2.2, Q1.2 (S), Q2.2 (S), R2.1, R3.1
unnamed: D1.2 (A), M1.2 (-), Q1.3 (D)
unnamed: D2.2 (A), M2.2 (-), Q2.3 (D)
unnamed: Q1.1 (G), R1.1
unnamed: Q2.1 (G), R4.1
PUMP_INPUT: J1.2, R1.2, R2.2

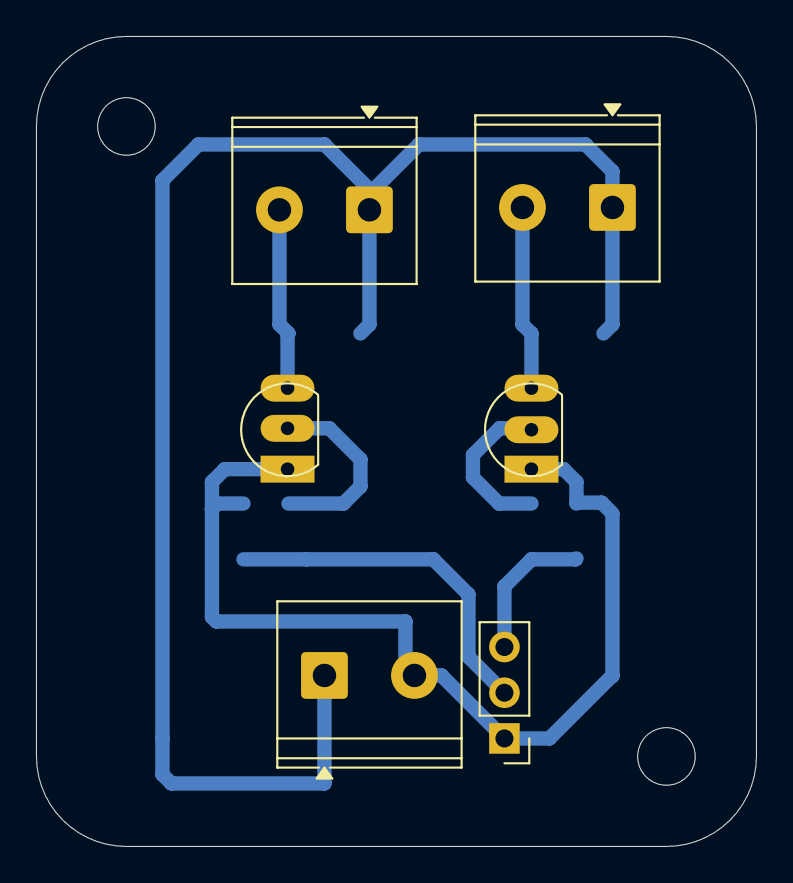
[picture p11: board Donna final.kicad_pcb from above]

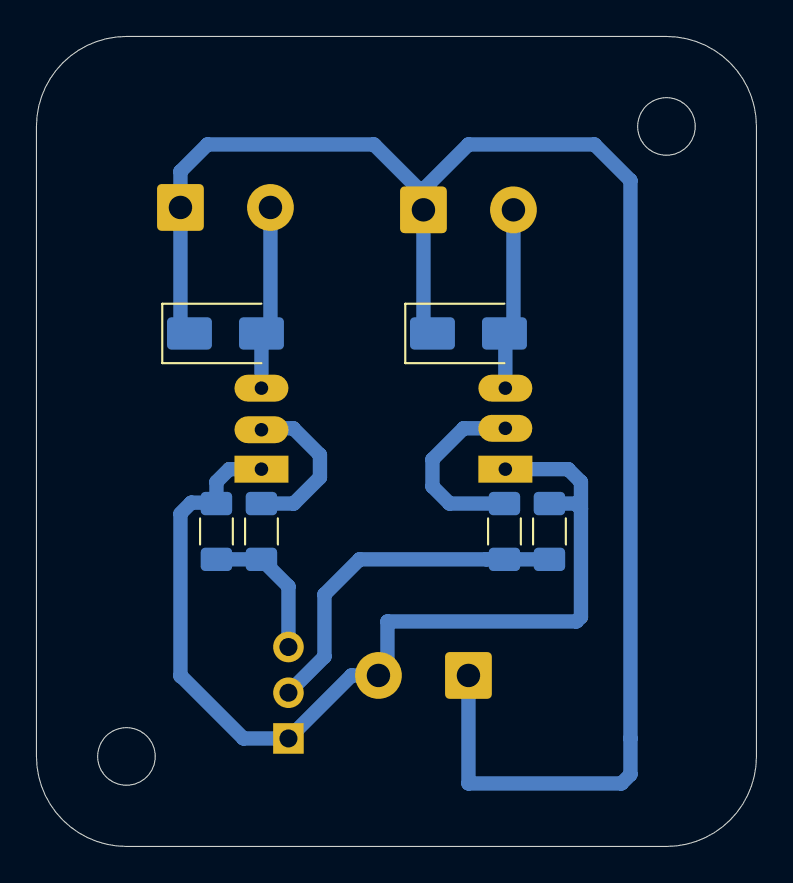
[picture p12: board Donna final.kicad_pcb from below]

Board: 2 copper layers, 40.0 x 45.0 mm, 14 parts (6 on the bottom side), 8 nets.

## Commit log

2026-06-13 Add additional image and description for camera support
2026-06-14 Update conception.md with Arduino and CNC Shield info
    Added section on Arduino and CNC Shield connection details.
2026-06-17 Mettre à jour le document des essais et résultats
    Ajout d'une image et mise à jour des résultats des essais sur les prototypes.
2026-06-17 Revise test results and improvements in documentation
    Updated the document with results and improvements from tests on printed wooden supports. Included images and detailed observations on design failures and enhancements.
